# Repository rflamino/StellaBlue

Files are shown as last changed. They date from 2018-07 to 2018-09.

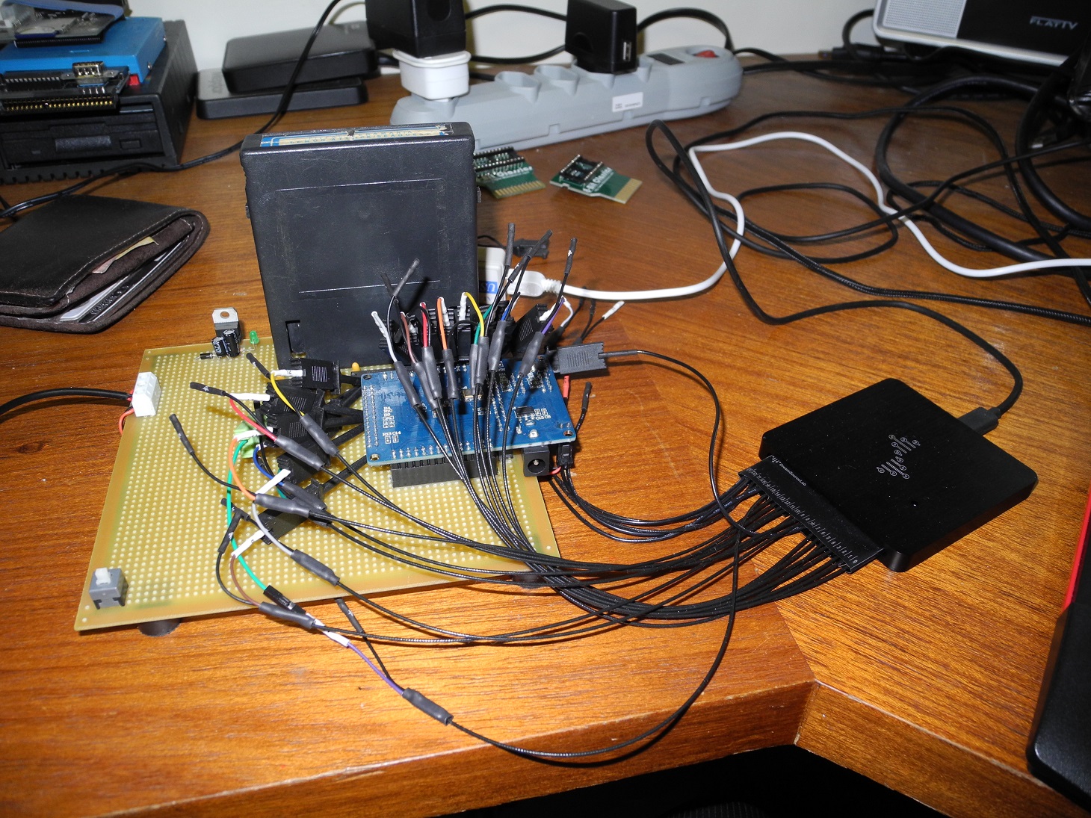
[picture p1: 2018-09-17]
pictures/setup.jpg

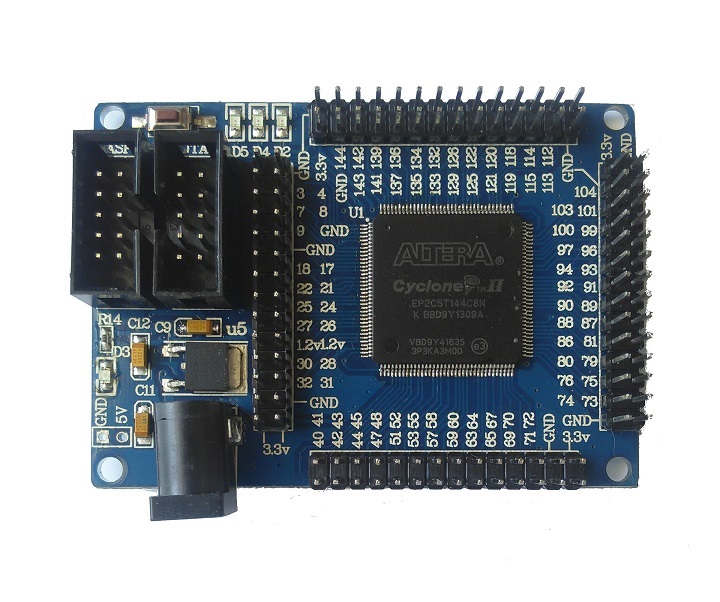
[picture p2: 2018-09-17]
doc/Cyclone-II-FPGA-Board-FZ0697-1.jpg

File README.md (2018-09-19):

# StellaBlue

StellaBlue AKA Retro2600: An FPGA clone of the Atari 2600 based on [Retromaster]'s cores.

-------------------------------------------------------------------------------

This project aims to use the hardware with the original atari cartridge configuration. Additionaly, the board also supports the original Paddle Controller (not fully tested) and the standard one.

The quartus project contains the glue logic to join the Retromaster's cores to the hardware (EP2C5T144 board - AKA "cheap FPGA blue board").

Using a fpga blaster; upload the "retro2600.pof" file via "Active Serial Programming". The device is EPCS4. Check the programming options "Program/Configure; Verifiy and Blank-Check".

The file "CartridgeGuide.stl" contains a Cartridge Guide socket. Print it! - with a 3D printer :)

rflamino AKA (Reinaldo de Sales Flamino)
Website:	[hackaday.io/rflamino]
email:		reinaldosflamino@gmail.com

[Danjovic]  AKA (Daniel Jose Viana)
Websites:	[danjovic.blogspot.com] & [hackaday.io/danjovic]
email:		danjovic@hotmail.com

[Danjovic]: <https://hackaday.io/danjovic/>
[hackaday.io/rflamino]: <https://hackaday.io/rflamino/>
[danjovic.blogspot.com]: <https://danjovic.blogspot.com/>
[hackaday.io/danjovic]: <https://hackaday.io/danjovic/>
[Danjovic]: <https://github.com/Danjovic/>
[Retromaster]: <https://retromaster.wordpress.com/a2601/>

First PCB!



Working!



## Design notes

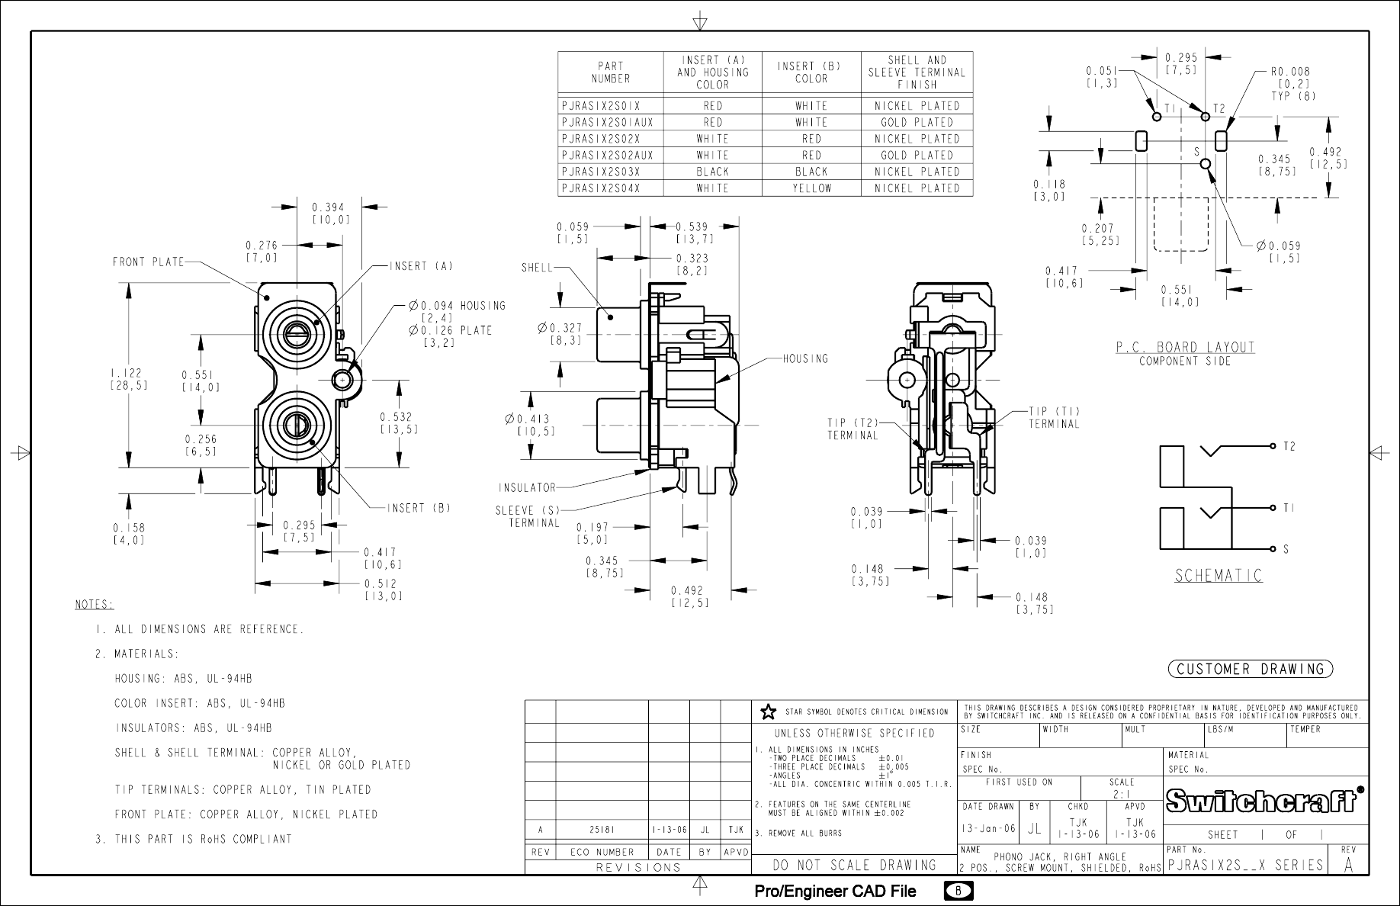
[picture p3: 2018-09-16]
doc/PJRAS1X2S01X-1.png

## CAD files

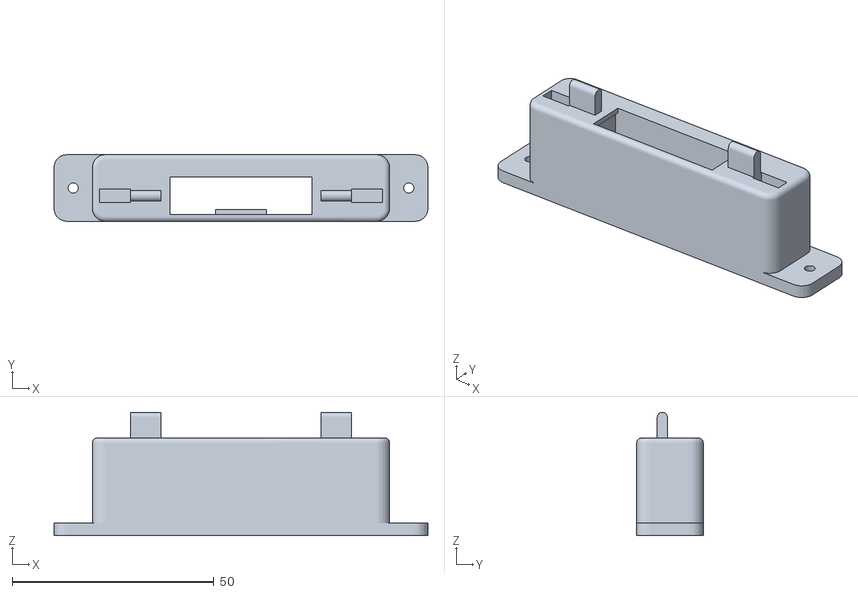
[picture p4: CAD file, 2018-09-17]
doc/CartridgeGuide.stl
92.7 x 16.5 x 30.6

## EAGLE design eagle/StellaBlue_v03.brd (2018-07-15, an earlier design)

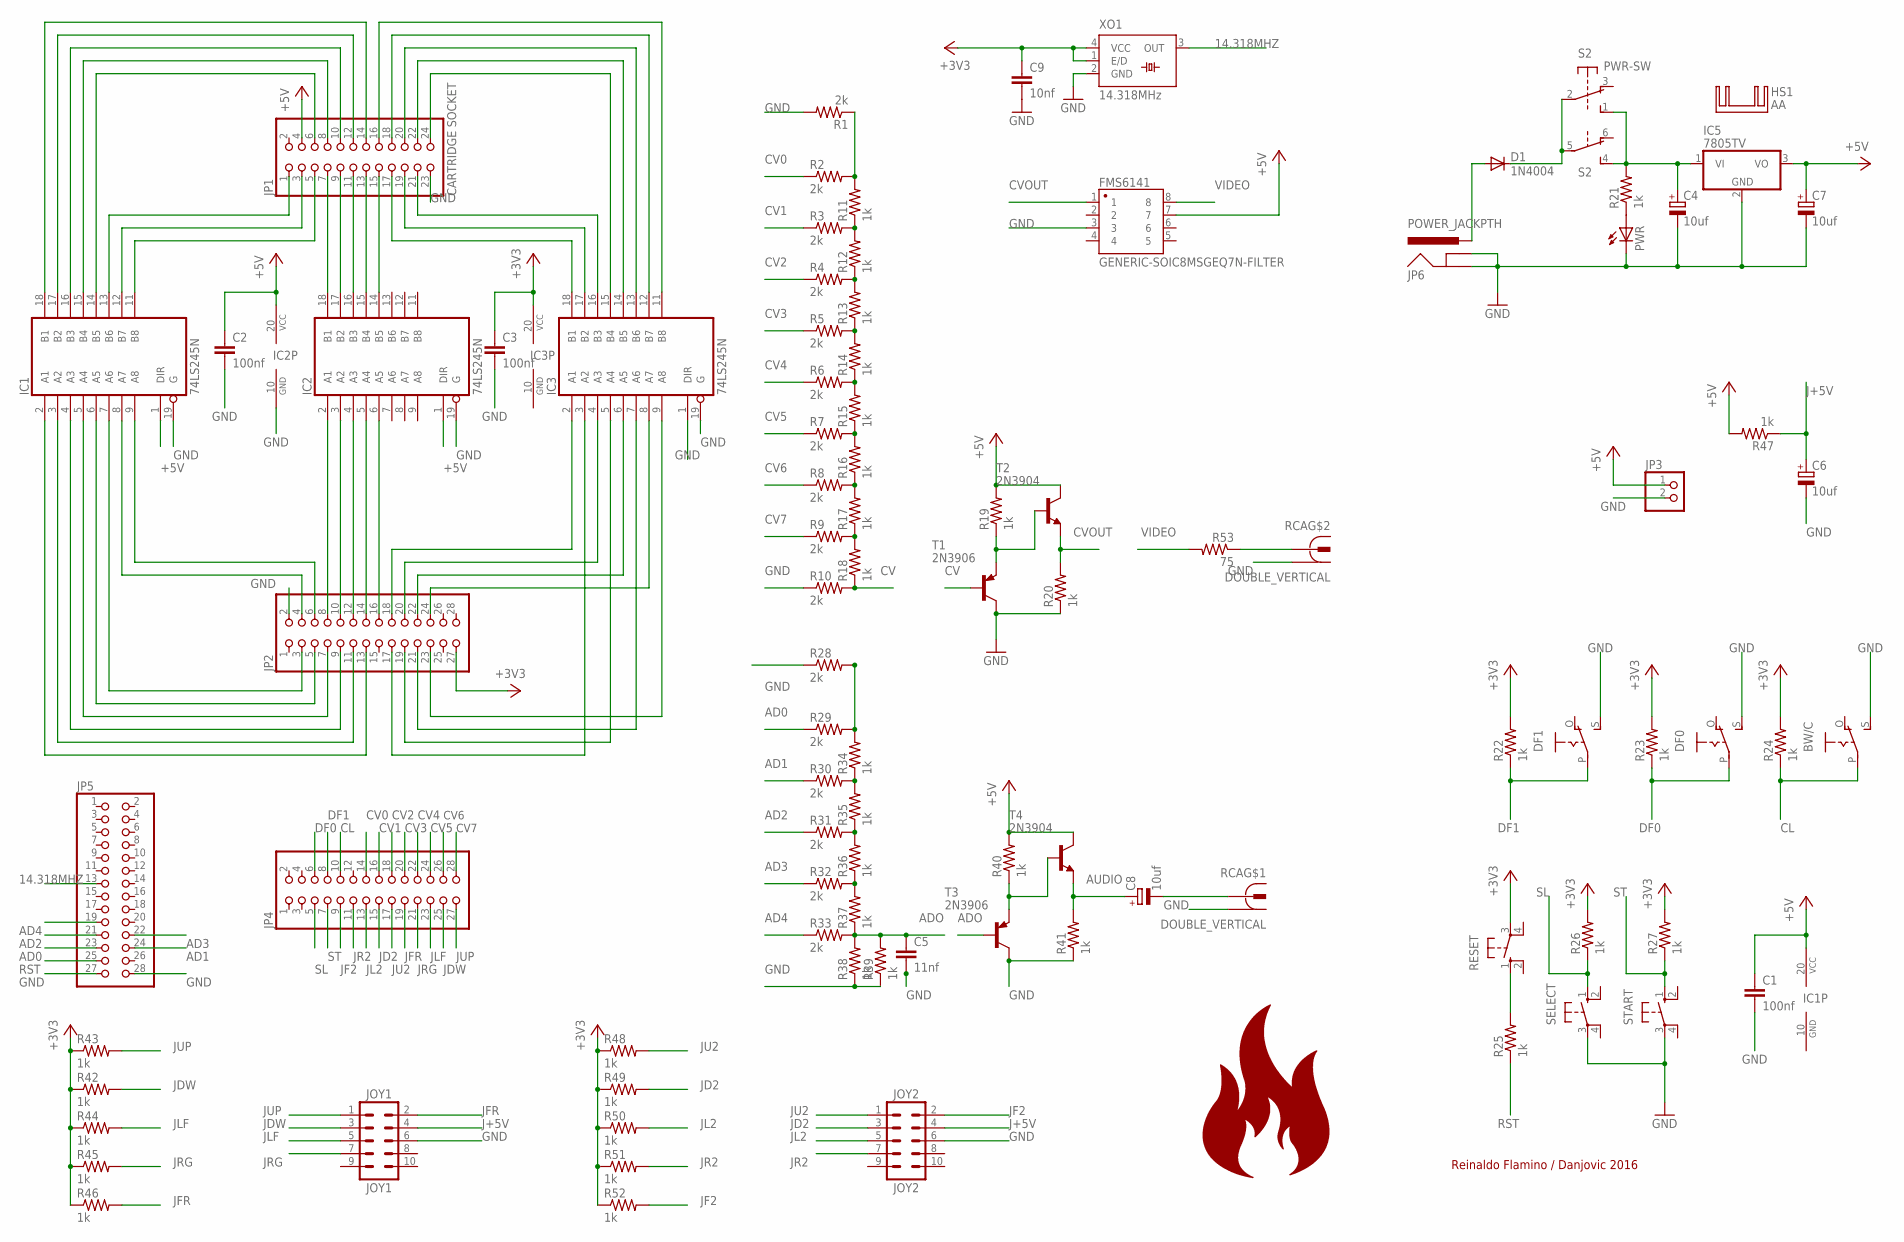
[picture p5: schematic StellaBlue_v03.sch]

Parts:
BW/C: EG1218S; EG1218
C1, C2, C3: 100nf; C5B2.5
C4, C7, C8: 10uf; E2,5-6
C5: 11nf; C5B2.5
C6: 10uf; TT2D6
C9: 10nf; C5B2.5
D1: 1N4004; DO41-10
DF0, DF1: EG1218S; EG1218
FMS6141: GENERIC-SOIC8MSGEQ7N-FILTER; SO08
HS1: AA
IC1, IC2, IC3: 74LS245N; DIL20
IC5: 7805TV; TO220V
JOY1: JOY1; 2X5-SHROUDED_LOCK
JOY2: JOY2; 2X5-SHROUDED_LOCK
JP1: CARTRIDGE SOCKET; ATARI2600_SLOT
JP2, JP4, JP5: PINHD-2X14; 2X14
JP3: PINHD-1X2/90; 1X02/90
JP6: POWER_JACKPTH; POWER_JACK_PTH
PWR: LED3MM
R1, R2, R3, R4, R5, R6, R7, R8, R9, R10, R28, R29, R30, R31, R32, R33: 2k; 0207/7
R11, R12, R13, R14, R15, R16, R17, R18, R19, R20, R21, R22, R23, R24, R25, R26, R27, R34, R35, R36, R37, R38, R39, R40, R41, R42, R43, R44, R45, R46, R47, R48, R49, R50, R51, R52: 1k; 0207/7
R53: 75; 0207/7
RCA: DOUBLE_VERTICAL; DOUBLE-VERTICAL
RESET: 10-XX; B3F-10XX
S2: PWR-SW; 9077-2
SELECT: 10-XX; B3F-10XX
START: 10-XX; B3F-10XX
T1, T3: 2N3906; TO92-EBC
T2, T4: 2N3904; TO92-EBC
XO1: 14.318MHz; SM77H

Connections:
14.318MHZ: JP5.13, XO1.3 (OUT)
+3V3: C3.1, C9.1, IC3.20 (VCC), JP2.27, R22.2, R23.2, R24.2, R26.2, R27.2, R42.1, R43.1, R44.1, R45.1, R46.1, R48.1, R49.1, R50.1, R51.1, R52.1, RESET.3, XO1.1 (E/D), XO1.4 (VCC)
+5V: C1.1, C2.1, C7.+, FMS6141.7, IC1.1 (DIR), IC1.20 (VCC), IC2.1 (DIR), IC2.20 (VCC), IC5.3 (VO), JP1.4, JP3.1, R19.2, R40.2, R47.2, T2.C, T4.C
AD0: JP5.23, R29.1
AD1: JP5.24, R30.1
AD2: JP5.21, R31.1
AD3: JP5.22, R32.1
AD4: JP5.19, R33.1
ADO: C5.1, R33.2, R37.1, R38.2, R39.2, T3.B
AUDIO: C8.+, R41.2, T4.E
CL: BW/C.P, JP4.10, R24.1
CV: R10.2, R18.1, T1.B
CV0: JP4.14, R2.1
CV1: JP4.16, R3.1
CV2: JP4.18, R4.1
CV3: JP4.20, R5.1
CV4: JP4.22, R6.1
CV5: JP4.24, R7.1
CV6: JP4.26, R8.1
CV7: JP4.28, R9.1
CVOUT: FMS6141.1, R20.2, T2.E
DF0: DF0.P, JP4.6, R23.1
DF1: DF1.P, JP4.8, R22.1
GND: BW/C.S, C1.2, C2.2, C3.2, C4.-, C5.2, C6.-, C7.-, C9.2, DF0.S, DF1.S, FMS6141.3, IC1.10 (GND), IC1.19 (G), IC2.10 (GND), IC2.19 (G), IC3.1 (DIR), IC3.10 (GND), IC3.19 (G), IC5.2 (GND), JOY1.6, JOY2.6, JP1.23, JP2.2, JP3.2, JP5.27, JP5.28, JP6.GND, JP6.GNDBREAK, PWR.K (C), R1.2, R10.1, R20.1, R28.1, R38.1, R39.1, R41.1, RCA.HG (1), RCA.LG (1), SELECT.3, START.3, T1.C, T3.C, XO1.2 (GND)
J+5V: C6.+, JOY1.4, JOY2.4, R47.1
JD2: JOY2.3, JP4.15, R49.2
JDW: JOY1.3, JP4.25, R42.2
JF2: JOY2.2, JP4.9, R52.2
JFR: JOY1.2, JP4.19, R46.2
JL2: JOY2.5, JP4.13, R50.2
JLF: JOY1.5, JP4.23, R44.2
JR2: JOY2.7, JP4.11, R51.2
JRG: JOY1.7, JP4.21, R45.2
JU2: JOY2.1, JP4.17, R48.2
JUP: JOY1.1, JP4.27, R43.2
unnamed: IC1.18 (B1), JP1.14
unnamed: IC1.17 (B2), JP1.12
unnamed: IC1.16 (B3), JP1.10
unnamed: IC1.15 (B4), JP1.8
unnamed: IC1.14 (B5), JP1.6
unnamed: IC1.13 (B6), JP1.1
unnamed: IC1.12 (B7), JP1.3
unnamed: IC1.11 (B8), JP1.5
unnamed: IC2.18 (B1), JP1.7
unnamed: IC2.17 (B2), JP1.9
unnamed: IC2.16 (B3), JP1.11
unnamed: IC2.15 (B4), JP1.13
unnamed: IC2.14 (B5), JP1.15
unnamed: IC3.18 (B1), JP1.17
unnamed: IC3.17 (B2), JP1.19
unnamed: IC3.16 (B3), JP1.21
unnamed: IC3.15 (B4), JP1.24
unnamed: IC3.14 (B5), JP1.22
unnamed: IC3.13 (B6), JP1.20
unnamed: IC3.12 (B7), JP1.18
unnamed: IC3.11 (B8), JP1.16
unnamed: IC1.2 (A1), JP2.13
unnamed: IC1.3 (A2), JP2.11
unnamed: IC1.4 (A3), JP2.9
unnamed: IC1.5 (A4), JP2.7
unnamed: IC1.6 (A5), JP2.5
unnamed: IC1.7 (A6), JP2.3
unnamed: IC1.8 (A7), JP2.4
unnamed: IC1.9 (A8), JP2.6
unnamed: IC2.2 (A1), JP2.8
unnamed: IC2.3 (A2), JP2.10
unnamed: IC2.4 (A3), JP2.12
unnamed: IC2.5 (A4), JP2.14
unnamed: IC2.6 (A5), JP2.16
unnamed: IC3.2 (A1), JP2.18
unnamed: IC3.3 (A2), JP2.17
unnamed: IC3.4 (A3), JP2.20
unnamed: IC3.5 (A4), JP2.19
unnamed: IC3.6 (A5), JP2.22
unnamed: IC3.7 (A6), JP2.21
unnamed: IC3.8 (A7), JP2.24
unnamed: IC3.9 (A8), JP2.23
unnamed: D1.A, JP6.PWR
unnamed: D1.C, S2.2, S2.5
unnamed: R1.1, R2.2, R11.2
unnamed: R3.2, R11.1, R12.2
unnamed: R53.1, RCA.LS (2)
unnamed: C4.+, IC5.1 (VI), R21.2, S2.1 (S), S2.4 (S)
unnamed: R4.2, R12.1, R13.2
unnamed: R5.2, R13.1, R14.2
unnamed: R6.2, R14.1, R15.2
unnamed: R7.2, R15.1, R16.2
unnamed: R8.2, R16.1, R17.2
unnamed: R9.2, R17.1, R18.2
unnamed: R19.1, T1.E, T2.B
unnamed: PWR.A, R21.1
unnamed: R25.2, RESET.1 (S)
unnamed: R28.2, R29.2, R34.2
unnamed: R30.2, R34.1, R35.2
unnamed: R31.2, R35.1, R36.2
unnamed: R32.2, R36.1, R37.2
unnamed: R40.1, T3.E, T4.B
unnamed: C8.-, RCA.HS (2)
RST: JP5.25, R25.1
SL: JP4.5, R26.1, SELECT.1 (S)
ST: JP4.7, R27.1, START.1 (S)
VIDEO: FMS6141.8, R53.2

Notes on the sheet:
Reinaldo Flamino / Danjovic 2016

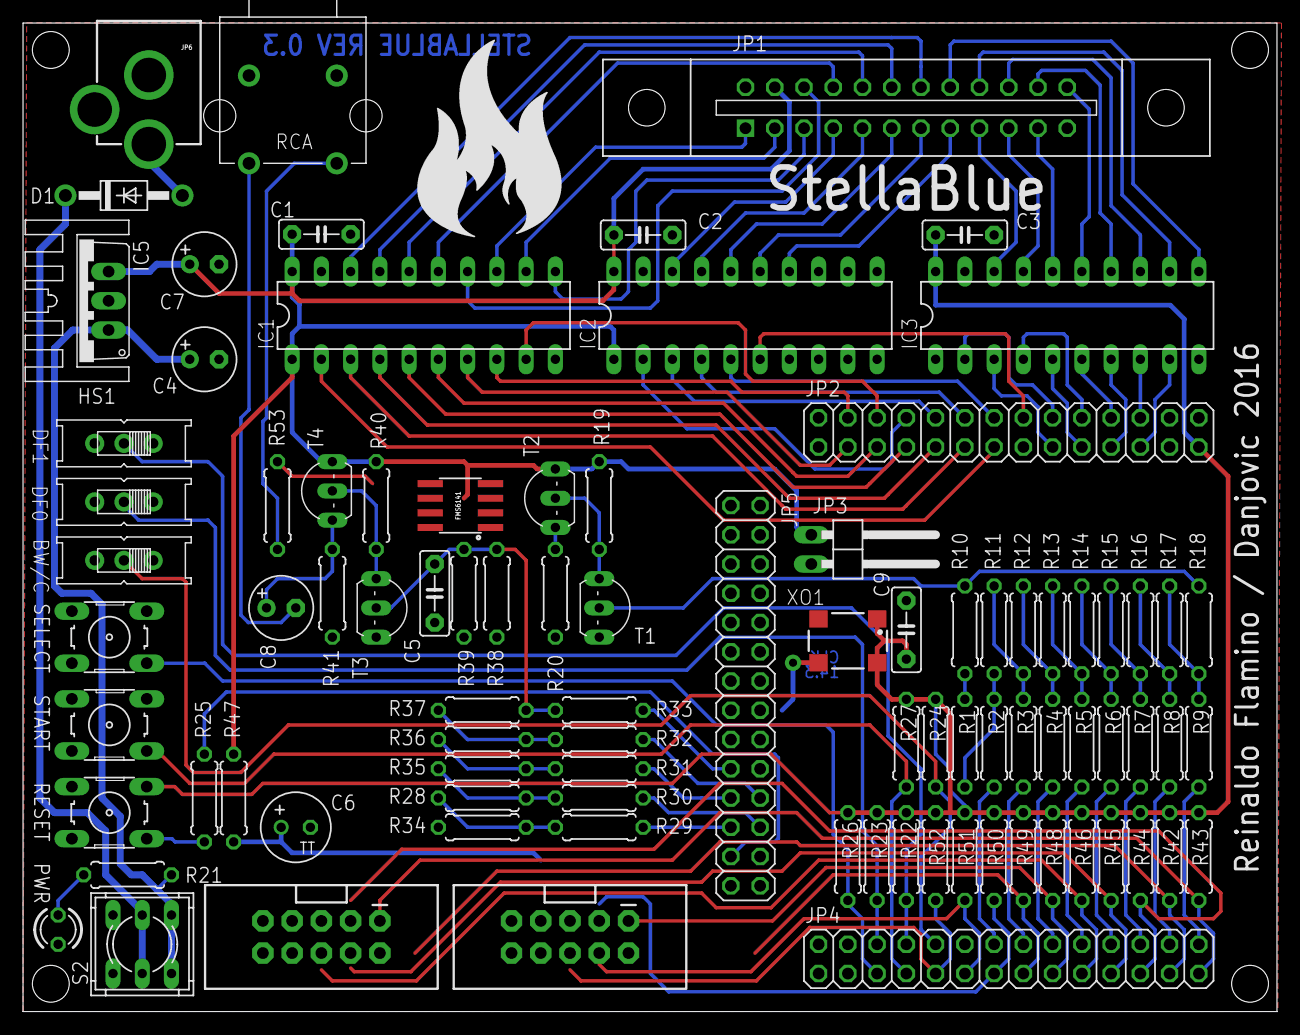
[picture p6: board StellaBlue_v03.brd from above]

Board: 2 copper layers, 108.9 x 85.8 mm, 91 parts (0 on the bottom side), 102 nets.

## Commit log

2016-08-31 first release
    [a2600.brd, a2600.sch]
2016-09-01 PCB layout manual enhancements. Still in progress
    [a2600.brd]
2016-09-02 Finished PCB routing, label placement still in work
    [StellaBlue.brd, StellaBlue.sch]
2016-09-03 labels replacement
    [StellaBlue.brd, StellaBlue.sch]
2016-09-03 labels positioning
    [StellaBlue.sch]
2016-09-05 Corrected board dimentions
    Daniel favor verificar
    [StellaBlue.brd]
2016-09-05 Corrected board dimension
    issue came from repositioning Labels
    [StellaBlue.brd]
2016-09-05 First PCB routing !
    [StellaBlue.brd, StellaBlue.sch]
2016-10-08 Added 14.318MHz crystal oscillator
    [StellaBlue.brd, StellaBlue.sch]
2016-11-26 Added script to generate RCA connector footprint
2018-09-16 core upload
    [retro2600.smp_dump.txt]
2018-09-17 descriptions and stl file

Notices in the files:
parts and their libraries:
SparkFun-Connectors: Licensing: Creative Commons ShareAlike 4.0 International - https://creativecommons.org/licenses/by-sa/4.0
